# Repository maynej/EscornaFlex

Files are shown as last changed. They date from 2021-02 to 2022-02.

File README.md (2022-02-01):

# EscornaFlex

EscornaFlex es una modificació de l'estructura original de Escornabot amb la flexibilitat de poder portar una placa de control 2.12 o 2.20, un sensor de distància per ultrasons i un lector RFID 

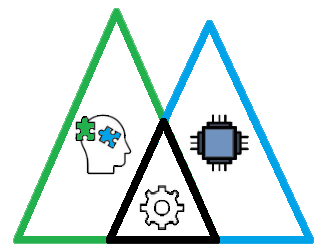
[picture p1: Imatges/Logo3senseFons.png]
Realitzada per [Jordi Mayné](https://github.com/maynej) des de Mechatronic Study 

Escornabot es un projecte obert (https://escornabot.com) 

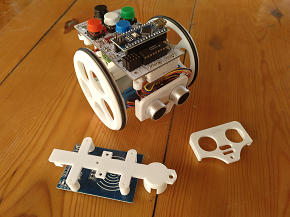
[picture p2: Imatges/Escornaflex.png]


Tota la [documentació es pot trobar en PDF](https://github.com/maynej/EscornaFlex/tree/master/Doc/). Inclós en llengua castellana.

STL per imprimir [aquí](https://github.com/maynej/EscornaFlex/tree/master/stl).

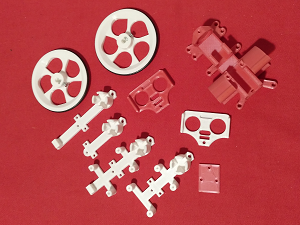
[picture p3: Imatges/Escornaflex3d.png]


## Llicència

Creative Commons Attribution-NoComercial-ShareAlike 4.0 International (CC BY-NC-SA 4.0)

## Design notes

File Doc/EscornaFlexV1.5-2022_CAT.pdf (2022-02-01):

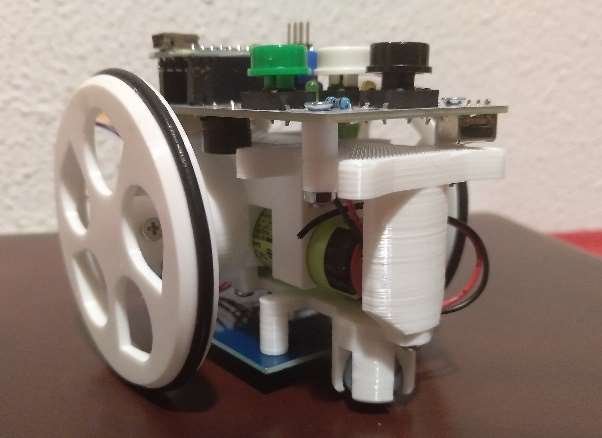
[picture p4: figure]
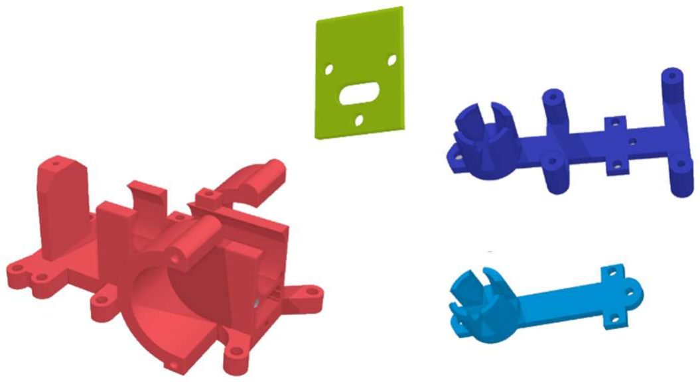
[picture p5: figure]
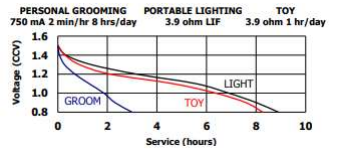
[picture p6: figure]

1 | EscornaFlex V.1.5 - 2022 | Jordi Mayné

## EscornaFlex

És un nou Escornabot ?, no. És una evolució de l'estructura Singularis, amb la particularitat de poder posar la placa CPU 2.12 o la CPU 2.20, per donar millor cabuda a les aplicacions amb Wifi o BT que a causa del seu consum es reduïa molt la vida de les piles, i més quan se li afegeix el lector de RFID, o noves aplicacions que aniran apareixent.

Para veure una mica aquests consums:
El mòdul BT HM-10 v4.0 en mode dormit consumeix 60uA, en mode actiu 8,5mA, però en mode RX està sobre els 15mA i en TX pot arribar a més de 25mA. Els consums depenen de la velocitat de transmissió, potencia de sortida i temps en espera i funcionament.
El mòdul Wifi ESP01 te diversos modes dormit que van des de 10uA fins 15mA, en mode RX està sobre els 56mA i en TX entre 120 y 170mA.
El mòdul RFID RC522 també te molts modes de treball, però tal com es farà servir en l’Escornabot s’utilitza com lector principalment que està sobre els 30mA y mentre espera una lectura pot estar entre 80uA fins a 4mA.
En definitiva, estem afegint consums importants, encara que siguin en temps “curts” , que minvarà la vida de las piles significativament. Les piles alcalines admeten un consum regular i el que menys els agrada son les puntes de corrent.
La solució es fer servir una bateria de Li-Ion que permet una major capacitat de carrega amb les mateixes dimensions. Anem a veure les diferencies:
Piles alcalines tipus AA (LR6) utilitzades fins ara, cada cèl·lula te unes dimensions de 14,5mm de diàmetre i 50,5mm de llarg, amb un pes de 23gr. El voltatge es de 1,5V i poden entregar entre 1700mAh i 3000mAh depenent del fabricant, i es necessiten 4 muntades en sèrie per donar un voltatge de sortida de 6V, però com es pot veure en la gràfica d’un fabricant, el voltatge va caient amb el consum i en el temps. Es a dir, els 6V duraran poc temps.

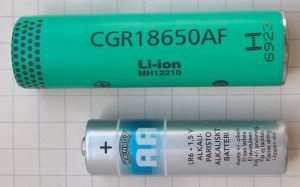
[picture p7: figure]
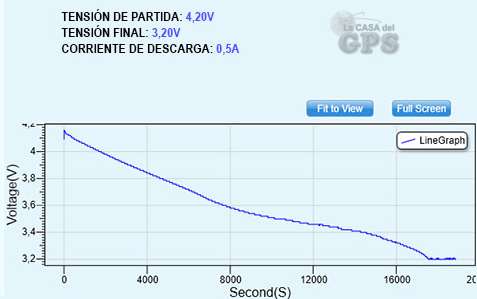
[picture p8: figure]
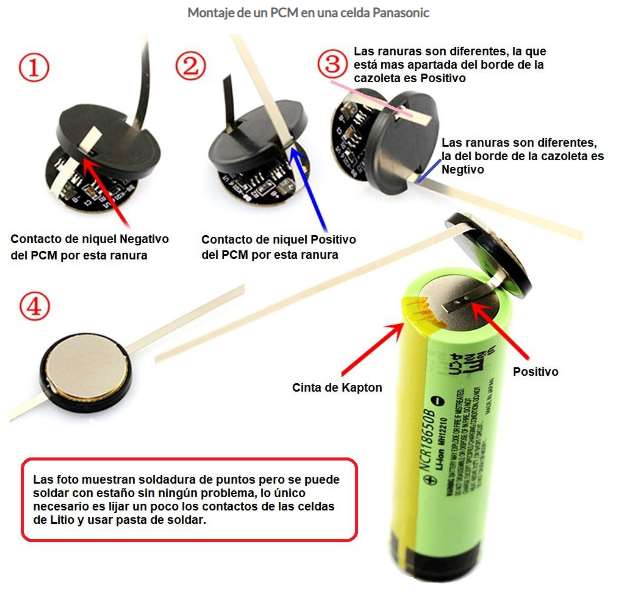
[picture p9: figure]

2 | EscornaFlex V.1.5 - 2022 | Jordi Mayné

Bateries Li-Ion tipus 18650 son de 3,7V i poden entregar entre 2000 i fins a 9000mAh, tenen unes dimensions de 18mm de diàmetre i 65mm de llarg, amb un pes de 49gr, son més cares que les piles (relativament) ja que son recarregables. Aquest model 18650 s’utilitza massivament en molts equips electrònics, com ordinadors portàtils, patinets i bicicletes elèctriques, llanternes, power-bank…

La gràfica mostra que, connectant una carrega de 0,5A al cap de 4,5h la tensió de la bateria arribarà als 3.2V amb que encara li queda carrega fins els 2.75V, que es la mínima permesa.
Un detall molt important, como sempre la seguretat. Les bateries Li-Ion poden “explotar”. Però no cal espantar-se, hi ha que fer les coses be. Per que “exploti” pot ser degut per les causes següents:
1. Curtcircuit (es pot evitar fent servir un circuit PCM o col·locant un fusible re-armable just en el terminal de la bateria).
2. Sobrevoltatge en la carrega, es a dir carregar-la amb un voltatge superior a l’especificada de 4.22V (es pot evitar fent servir un circuit de carrega apropiat).
3. Temperatura de la bateria (evitant una font de calor propera a ella).

Es poden comprar bateries 18650 amb la
protecció incorporada, per no confondre és
molt fàcil de detectar si la inclou o no, simplement per la longitud, en lloc de mesurar 65mm passa a tenir 69mm en incorporar el circuit de protecció.
Les bateries que inclouen protecció són per anar en un "porta-bateries", és a dir sense terminals per soldar, fins ara no s'han trobat que l'incorporin en les bateries amb terminals, però pot ser que en breu es trobin també en aquest tipus .
Una solució és incorporar un circuit PCM, que protegeix contra curtcircuits, sobre-voltatges i obre el circuit quan arriba la bateria a 2,75V.

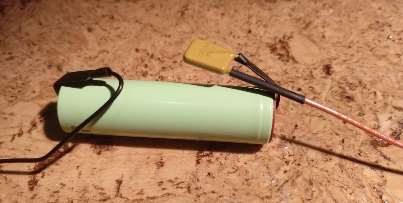
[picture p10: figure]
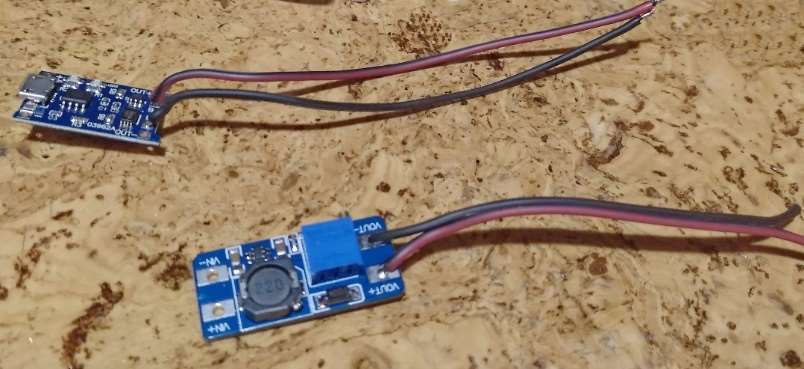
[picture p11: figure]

3 | EscornaFlex V.1.5 - 2022 | Jordi Mayné

Una altra solució no tan sofisticada i més senzilla és posar un fusible rearmable de 0,65A al terminal de la bateria, protegirà només contra curtcircuits, però suficient.

Circuit de control:

Per carregar la bateria es parteix d'una connexió USB, que és de 5V, i amb un circuit mòdul de càrrega TP4056 que protegeix perquè no pugui arribar a la bateria un voltatge superior a 4,2V i que no li pugui arribar un corrent de càrrega superior a 1A.
La bateria lliura un voltatge entre 3 fins 4,2V, i amb un altre mòdul MT3608 Step-up puja el voltatge regulat a 6V (el valor de sortida s’ajusta amb el potenciòmetre que
inclou. Aquest circuit admet voltatge de 2 a 24V d'entrada i la sortida ajustable entre
5 fins 28V, amb un corrent fins 2A.
La sortida d’aquest circuit pot conectarse (una vegada ajustat a 6V) a l’entrada de la pcb CPU.

Nota important: S’ha detectat que algun step-up no aguanta les puntes de corrent dels motors, i no funciona l’Escornabot, nomès les llums i el pitu del brunzidor. Llavors es soluciona col.locant un condensador electrolític de 1000uF 10V en les bornas d’alimentació.

Preparació del muntatge:
Abans de soldar les connexions entre les plaques, cal revisar si entren bé les plaques en la guia suport que hi ha sota la bateria de l'estructura, depèn del fabricant de les plaques pot entrar molt justa o no tant, es pot solucionar llimant els laterares del pcb de la placa. Un cop ajustades, es pot començar a realitzar les connexions.
Primer soldar a la placa USB els cables a B+ i B- que aniran a la bateria i en la placa step-up els cables en Vout+ i Vout- que aniran al connector de la placa CPU.

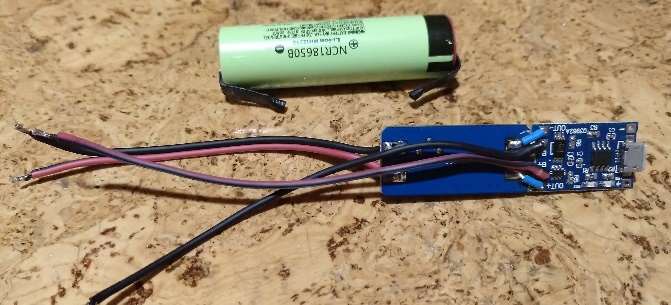
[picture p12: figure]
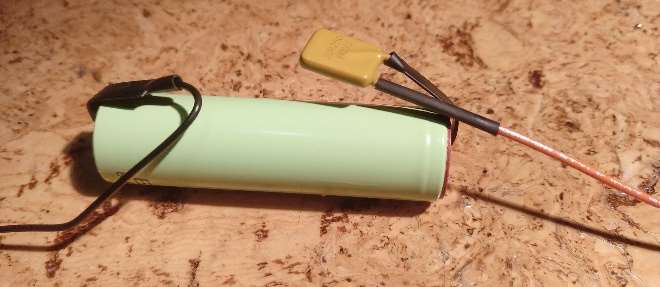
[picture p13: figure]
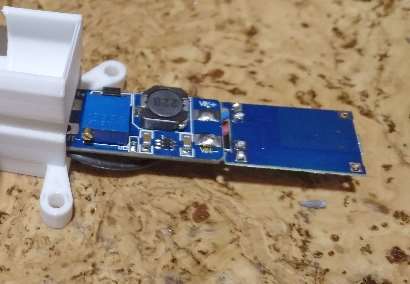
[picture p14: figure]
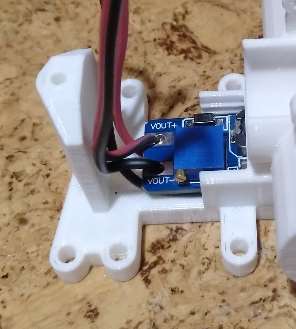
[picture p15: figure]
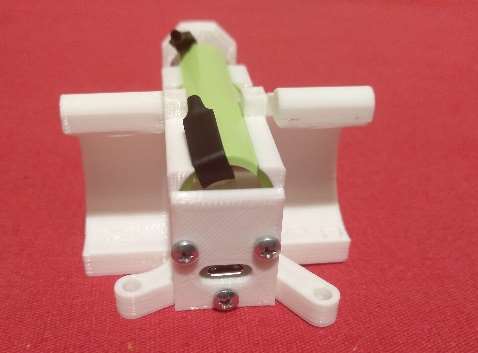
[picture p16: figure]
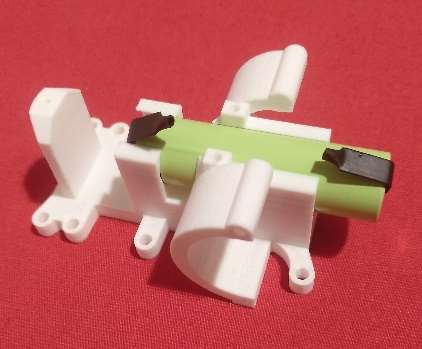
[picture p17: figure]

4 | EscornaFlex V.1.5 - 2022 | Jordi Mayné

Seguidament col·locar la placa de càrrega USB en posició amb els components en la part superior i la placa step-up amb els components en la part inferior, així coincidiran les sortides Out+ i Out- del carregador amb Vin+ i Vin- del step-up, amb fil rígid fer aquestes connexions (a la foto es poden apreciar de color blau). Es fan amb fil rígid perquè formin un bloc compacte per poder-les inserir en l'estructura, ja que entrarà expressament molt justes perquè no es desplacin.

Soldar un fusible rearmable de 0,65A al positiu de la bateria i aïllar amb tub termoretàctil aquestes connexions.

Inserir les dues plaques en l'estructura amb totes les connexions realitzades, entrarà molt justa, col·locar els cables molt plans per ajudar a que llisqui bé.

D’aquesta manera quedarà accesible el potenciómetre d’ajust de la tensió de sortida, que s’ajustará a 6V. Col·locar la bateria en el habitacle desplaçant-la fins al final.

Col·locar la tapa que cobrirà el connector USB i la bateria

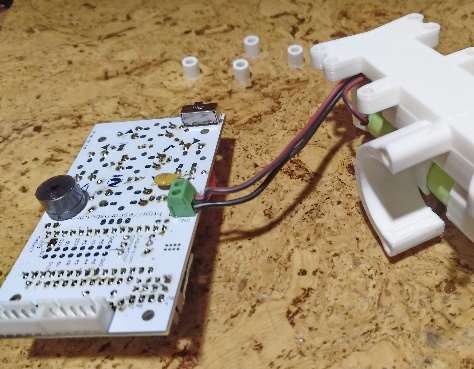
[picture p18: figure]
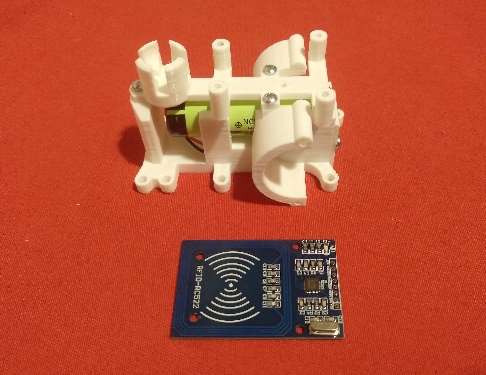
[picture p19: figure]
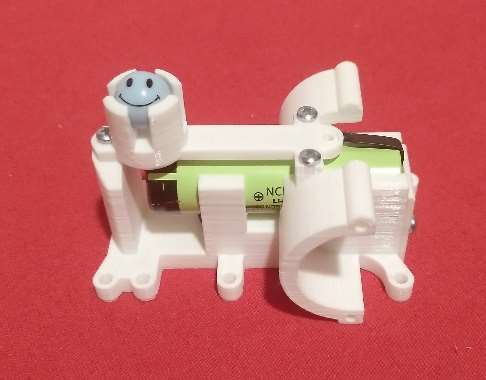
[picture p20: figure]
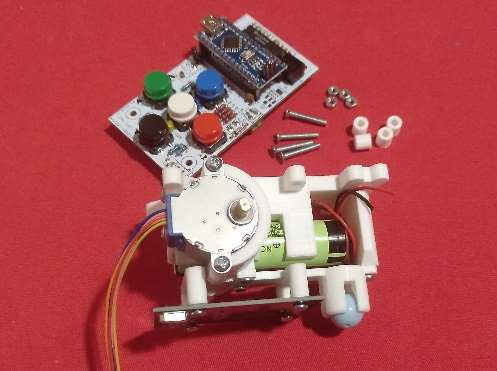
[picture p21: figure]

5 | EscornaFlex V.1.5 - 2022 | Jordi Mayné

Connectar els cables de sortida de la placa step-up al connector d’alimentació de la CPU. Soldar els cables de la placa de USB B+ al fusible rearmable de la batería i B- al negatiu.

Hi ha dues opcions del suport de bola “boja”, per incorporar la placa de RFID RC522 o sense.

Es munten els motors i la placa CPU corresponent (2.12 o 2.20) amb l’ajut de 4 separadors i 4 cargols M3x20 y 4 femelles M3.

Es connecten els cables de cada motor al seu connector corresponent (motor dret a la dreta i motor esquerra a l’esquerra).

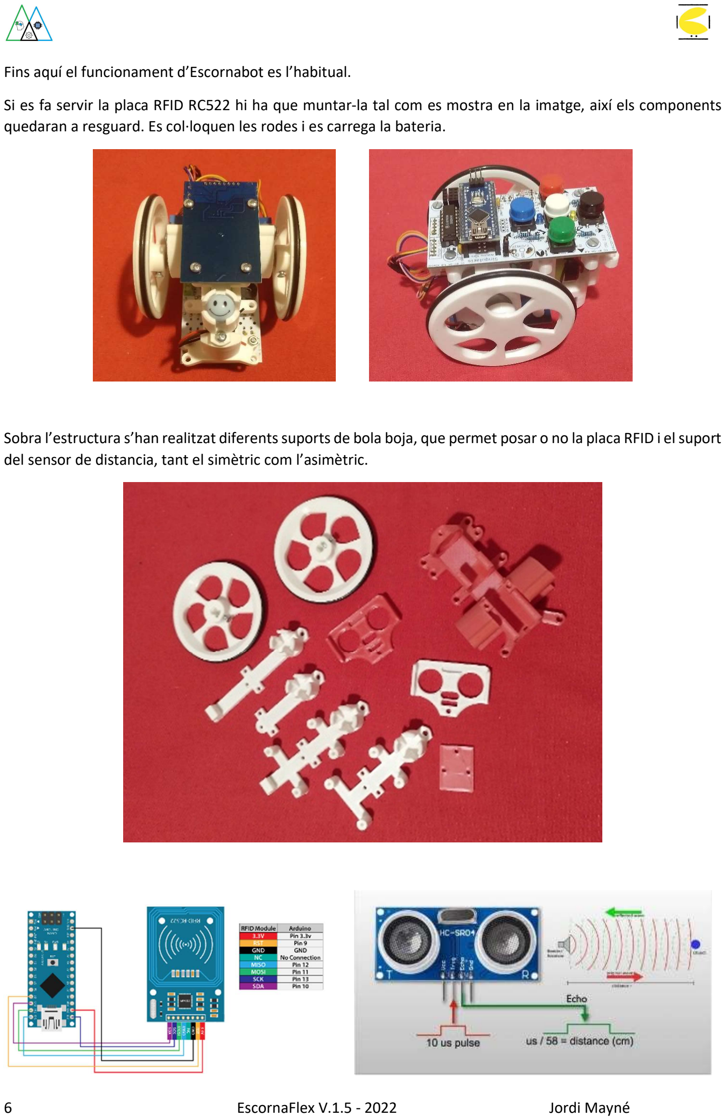
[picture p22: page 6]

6 | EscornaFlex V.1.5 - 2022 | Jordi Mayné

Fins aquí el funcionament d’Escornabot es l’habitual.
Si es fa servir la placa RFID RC522 hi ha que muntar-la tal com es mostra en la imatge, així els components quedaran a resguard. Es col·loquen les rodes i es carrega la bateria.

Sobra l’estructura s’han realitzat diferents suports de bola boja, que permet posar o no la placa RFID i el suport del sensor de distancia, tant el simètric com l’asimètric.

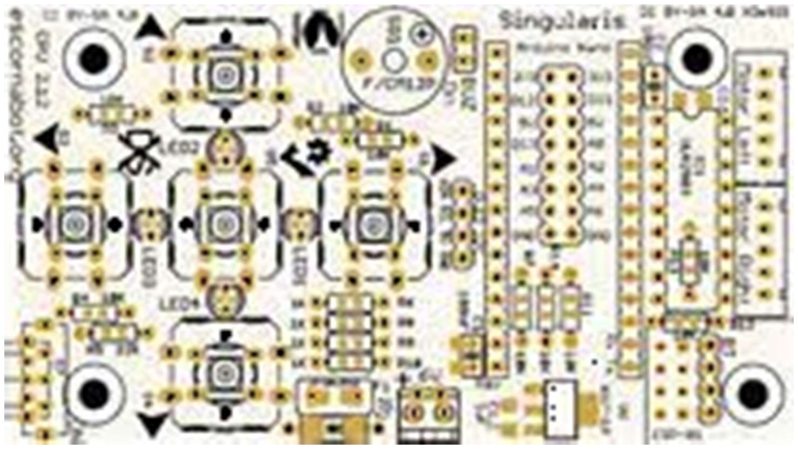
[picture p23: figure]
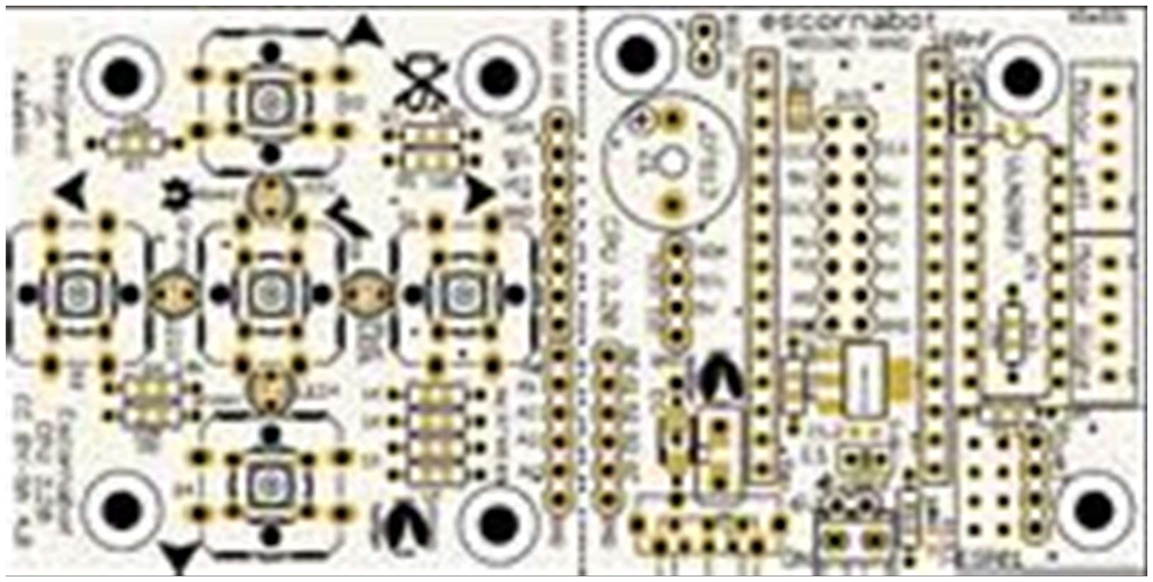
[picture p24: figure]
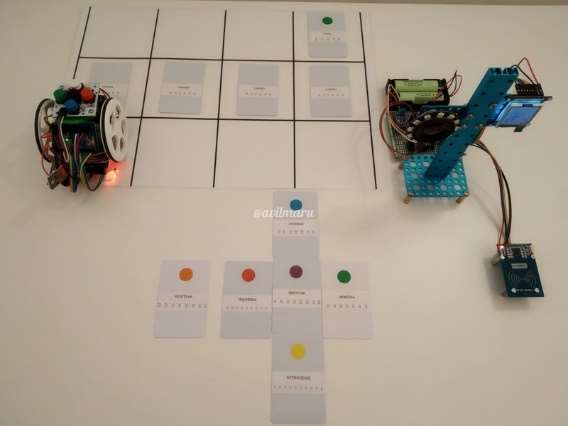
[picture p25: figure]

7 | EscornaFlex V.1.5 - 2022 | Jordi Mayné

Es pot utilitzar tant el mòdul de Wifi como el de Bluetooth, però, es més recomanable usar el de Bluetooth i l’aplicació per Android.

Mòdul Wifi | Mòdul Bluetooth i aplicació per Android

En quant les plaques CPU que es poden muntar es mostren a continuació.

CPU 2.12 | CPU2.20

Tota la documentació i els STL es troba disponible en el github: https://github.com/maynej/EscornaFlex

Per el funcionament RFID referir-se al bon treball d’Ángel Villanueva en el “Proyecto para niños y niñas con discapacidad visual o ceguera”.

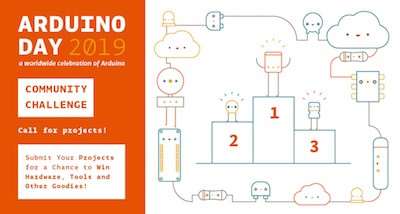
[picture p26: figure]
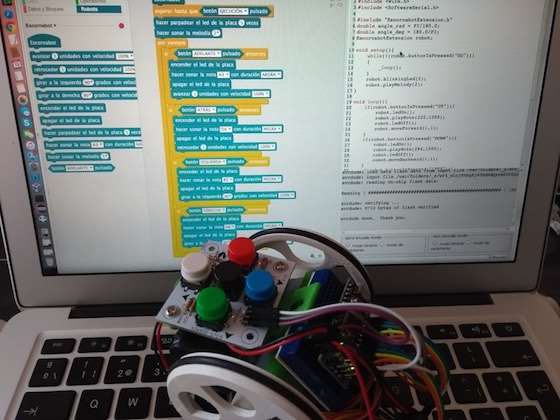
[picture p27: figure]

8 | EscornaFlex V.1.5 - 2022 | Jordi Mayné

Aquest projecte va ser presentat en el concurs internacional “Arduino Day Community Challenge” el dissabte 16 de Març de 2019 a Milà resultant guanyador en la categoria d’innovació social.

http://www.mecatronicalab.es/escornabot-proyecto-para-ninos-con-discapacidad-visual-o-ceguera/ A més, la magnífica aplicació EscornaVoz: http://www.mecatronicalab.es/escornavoz/

i l’extensió per Programar ESCORNABOT AMB MBLOCK basat en Scratch 2.0 http://www.mecatronicalab.es/programando-escornabot-con-mblock/

¡¡¡Moltes gràcies a tots els col·laboradors del projecte Escornabot, fa que dia a dia segueixi creixent !!!

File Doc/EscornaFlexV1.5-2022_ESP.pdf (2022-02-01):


1 | EscornaFlex V.1.5 - 2022 | Jordi Mayné

## EscornaFlex

¿Es un nuevo Escornabot?, no. Es una evolución de la estructura Singularis, con la particularidad de poder poner la placa CPU 2.12 y la CPU 2.20, para dar mejor cabida a las aplicaciones con Wifi o BT que debido a su consumo se reducía mucho la vida de las pilas, y más cuando se le añade el lector de RFID, o nuevas aplicaciones que irán apareciendo.

Para ver un poco estos consumos:
El módulo BT HM-10 v4.0 en modo dormido consume 60uA, en modo activo 8,5mA, pero en modo RX está sobre los 15mA y en TX puede llegar a más de 25mA. Los consumos dependen de la velocidad de transmisión, potencia de salida y tiempo en espera y funcionamiento.
El módulo Wifi ESP01 tiene varios modos de trabajo “dormido” que van desde los 10uA hasta los 15mA, en modo RX está sobre los 56mA y en TX entre 120 y 170mA.
El módulo RFID RC522 también tiene muchos modos de trabajo, pero en su uso actual en el Escornabot se utiliza como lector principalmente que está sobre los 30mA y mientras espera una lectura puede estar entre 80uA hasta los 4mA.
En definitiva, estamos añadiendo consumos importantes, aunque sean en tiempos “cortos”, que mermarán la vida de las pilas significativamente. Las pilas alcalinas admiten un consumo regular y lo que menos les gusta son las puntas de corriente.
La solución es usar un batería de Li-Ion que permiten una mayor capacidad de carga con el mismo tamaño. Vamos a ver las diferencias:
Pilas alcalinas tipo AA (LR6) utilizadas hasta ahora, cada célula tiene un tamaño de 14,5mm de diámetro y 50,5mm de largo, con un peso de 23gr. El voltaje es de 1,5V y pueden entregar entre 1700mAh y 3000mAh dependiendo del fabricante, y se necesitan 4 montadas en serie para dar un voltaje de salida de 6V, pero como se puede ver en la gráfica de un fabricante, el voltaje va cayendo con el consumo y en el tiempo. Es decir, los 6V durarán poco tiempo.


2 | EscornaFlex V.1.5 - 2022 | Jordi Mayné

Baterías Li-Ion tipo 18650 son de 3,7V y pueden entregar entre 2000 y hasta 9000mAh, tienen un tamaño de 18mm de diámetro y 65mm de largo, con un peso de 49gr, son más caras que las pilas (relativamente) ya que son recargables. Este modelo 18650 se utiliza masivamente en muchos equipos electrónicos, como ordenadores portátiles, patinetes y bicicletas eléctricas, linternas, power-bank…

La gráfica muestra que, conectando una carga de 0,5A al cabo de 4,5h la tensión de la batería llegará a los 3,2V, con lo que aún le queda carga hasta llegar a los 2,75V, que es la mínima permitida.
Un detalle muy importante, como siempre la seguridad. Las baterías Li-Ion pueden “explotar”. Pero no hay que asustarse, hay que hacer las cosas bien. Para que “explote” puede ser debido por las causas siguientes:
1. Cortocircuito (se puede evitar usando un circuito PCM o un colocando un fusible re-armable justo en el terminal de la batería).
2. Sobrevoltaje en la carga, es decir cargarla con un voltaje superior a la especificada 4.22V (se puede evitar usando un circuito de carga apropiado).

### 3. Temperatura de la batería (se

puede evitar evitando una fuente
de calor próxima a ella).Se pueden
comprar baterías 18650 con la protección incorporada, para no confundirse es muy fácil de detectar si la incluye o no, simplemente por la longitud, en lugar de medir 65mm pasa a tener 69mm al incorporar el circuito de protección.
Las baterías que incluyen protección son para ir en un “porta-baterías”, es decir sin terminales para soldar, hasta ahora no se han encontrado que lo incorporen en las baterías con terminales, pero puede ser que en breve se encuentren también en este tipo.


3 | EscornaFlex V.1.5 - 2022 | Jordi Mayné

Una solución es incorporar un circuito PCM, que protege contra cortocircuitos, sobrevoltajes y abre el circuito cuando llega la batería a 2,75V.
Otra solución no tan sofisticada y más sencilla es poner un fusible re-armable de 0,65A en el terminal de la batería, protegerá solamente contra cortocircuitos, pero suficiente.

Circuito de control:

Para cargar la batería se parte de una conexión USB, que es de 5V, y con un circuito módulo de carga TP4056 que protege para que no pueda llegar a la batería un voltaje superior a 4,2V y que no le pueda llegar una corriente de carga superior a 1A.
La batería entrega un voltaje entre 3 hasta 4,2V, entonces con otro módulo MT3608 Step-up sube el voltaje regulado a 6V (es ajustable el valor de salida, ajustando el potenciómetro que incluye. Este circuito admite voltaje de 2 a 24V de entrada y la
salida ajustable entre 5 hasta 28V, con una corriente hasta 2A.
La salida de este circuito puede conectarse (una vez ajustado a 6V) a la entrada de la pcb CPU.

Nota importante: Se ha detectado que algun step-up no aguanta las puntas de corriente de los motores, y entonces no funciona el Escornabot, solo las luces y el pitido del zumbador. Entonces se soluciona colocando un condensador electrolítico de 1000uF 10V en las bornas de alimentación.
Preparación del montaje:
Antes de soldar las conexiones entre las placas, hay que revisar si entran bien las placas en la guía soporte que hay debajo de la batería de la estructura, depende del fabricante de las placas puede entrar muy justa o no tanto, se puede solucionar limando los laterares del pcb de la placa. Una vez ajustadas, se puede empezar a realizar las conexiones.
Primero soldar en la placa USB los cables en B+ y B- que irán a la batería y en la placa step-up los cables en Vout+ y Vout- que irán al conector de la placa CPU.


4 | EscornaFlex V.1.5 - 2022 | Jordi Mayné

Seguidamente colocar la placa de carga USB en posición con los componentes en la parte superior y la placa step-up con los componentes en la parte inferior, así coincidirán las salidas Out+ y Out- del cargador con Vin+ y Vin- de step-up, con hilo rígido hacer estas conexiones (en la foto se pueden apreciar de color azul). Se hacen con hilo rígido para que formen un bloque compacto para poderlas insertar en la estructura, ya que entrará expresamente muy justas para que no se desplacen.

Soldar un fusible rearmable de 0,65A en el positivo de la batería y aislar con tubo termoretàctil estas conexiones.

Insertar las dos placas en la estructura con todas las conexiones realizadas, entrará muy justa, colocar los cables muy planos para ayudar a que se deslice bien.

De esta manera quedará accesible el potenciómetro de ajuste de la tensión de salida, que se ajustará a 6V. Colocar la batería en el habitáculo desplazando la batería por el habitáculo.

Colocar la tapa que cubrirá el conector USB y la batería


5 | EscornaFlex V.1.5 - 2022 | Jordi Mayné

Conectar los cables salida de la placa step-up al conector de alimentación de la CPU. Soldar los cables de la placa de USB B+ al fusible rearmable de la batería y B- al negativo.

Hay dos opciones del soporte de bola “loca”, para incorporar la placa de RFID RC522 o sin.

Se montan los motores y la placa CPU correspondiente (2.12 o 2.20) con la ayuda de 4 separadores y 4 tornillos M3x20 y 4 tuercas M3.

Se conectan los cables de cada motor a su conector correspondiente (derecho a la derecha e izquierdo a izquierda).


6 | EscornaFlex V.1.5 - 2022 | Jordi Mayné

Hasta aquí el funcionamiento del Escornabot es el habitual.
Si se usa la placa RFID hay que montarla tal como se muestra en la imagen, así los componentes quedarán a salvo. Se colocan las ruedas y se carga la batería. El funcionamiento de Escornabot es el habitual.

Sobre la estructura se han realizado diferentes soportes de bola loca, que permite insertar o no la placa RFID y el soporte del sensor de distancia, tanto el simétrico o asimétrico.


7 | EscornaFlex V.1.5 - 2022 | Jordi Mayné

Se puede usar tanto el módulo de Wifi como el de Bluetooth, pero es más recomendable usar el de Bluetooth y la aplicación de Android.

Módulo Wifi | Módulo Bluetooth y aplicación para Android

En cuanto a las placas CPU que se pueden montar se muestran a continuación.

CPU 2.12 | CPU2.20

Toda la documentación y STL se encuentra disponible en el github: https://github.com/maynej/EscornaFlex

Para el funcionamiento RFID referirse al buen trabajo de Ángel Villanueva en el “Proyecto para niños y niñas con discapacidad visual o ceguera”.


8 | EscornaFlex V.1.5 - 2022 | Jordi Mayné

Este proyecto fue presentado en el concurso internacional “Arduino Day Community Challenge” celebrado el sábado 16 de marzo de 2019 en Milán resultando ganador en la categoría de innovación social.

http://www.mecatronicalab.es/escornabot-proyecto-para-ninos-con-discapacidad-visual-o-ceguera/

Además, la magnífica aplicación EscornaVoz http://www.mecatronicalab.es/escornavoz/

y la extensión para Programar ESCORNABOT CON MBLOCK basado en Scratch 2.0 http://www.mecatronicalab.es/programando-escornabot-con-mblock/

¡¡¡Muchas gracias a todos los colaboradores del proyecto Escornabot, hace que día a día siga creciendo!!!

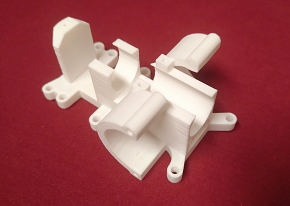
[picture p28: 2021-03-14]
Imatges/CosEscornaflex.png

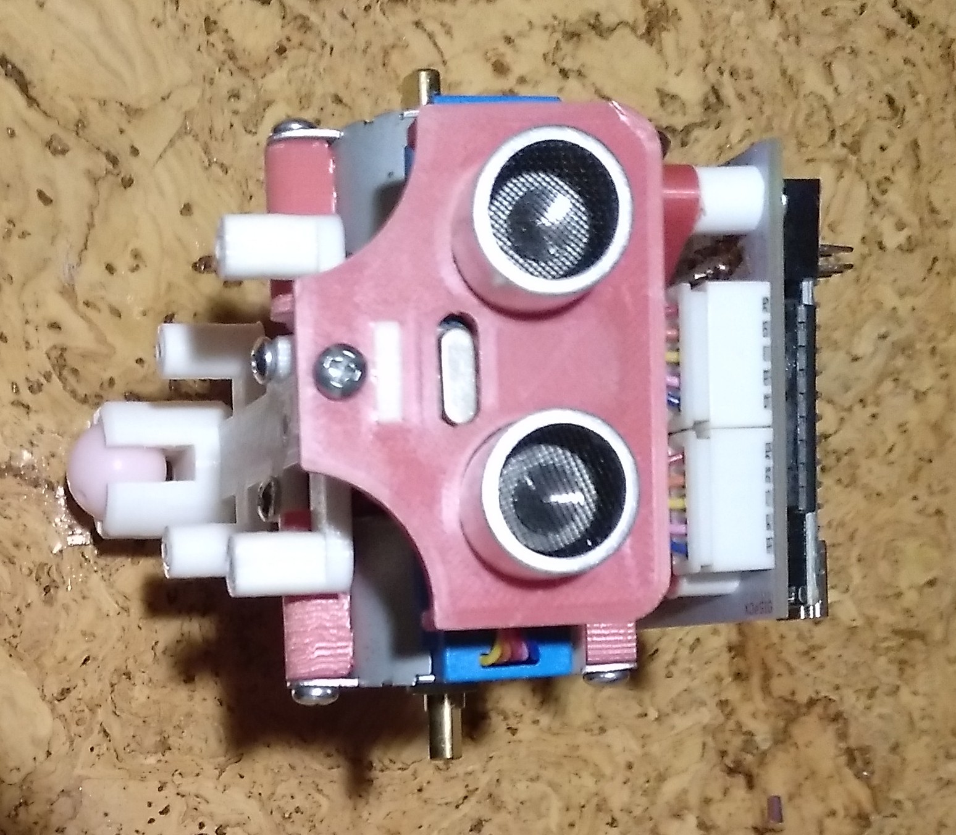
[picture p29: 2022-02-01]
Imatges/MVIMG_20191003_181412_255~2.jpg

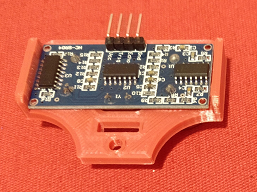
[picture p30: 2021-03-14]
Imatges/SensorUltrasons.png

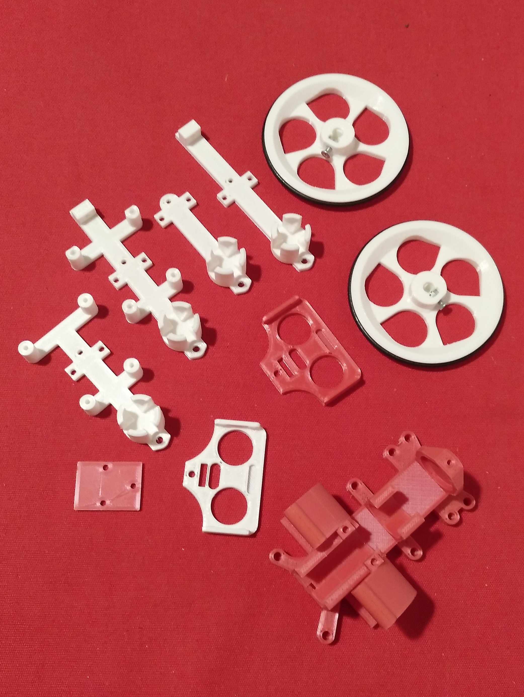
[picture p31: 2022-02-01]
Imatges/MVIMG_20191001_185606_342_2.jpg

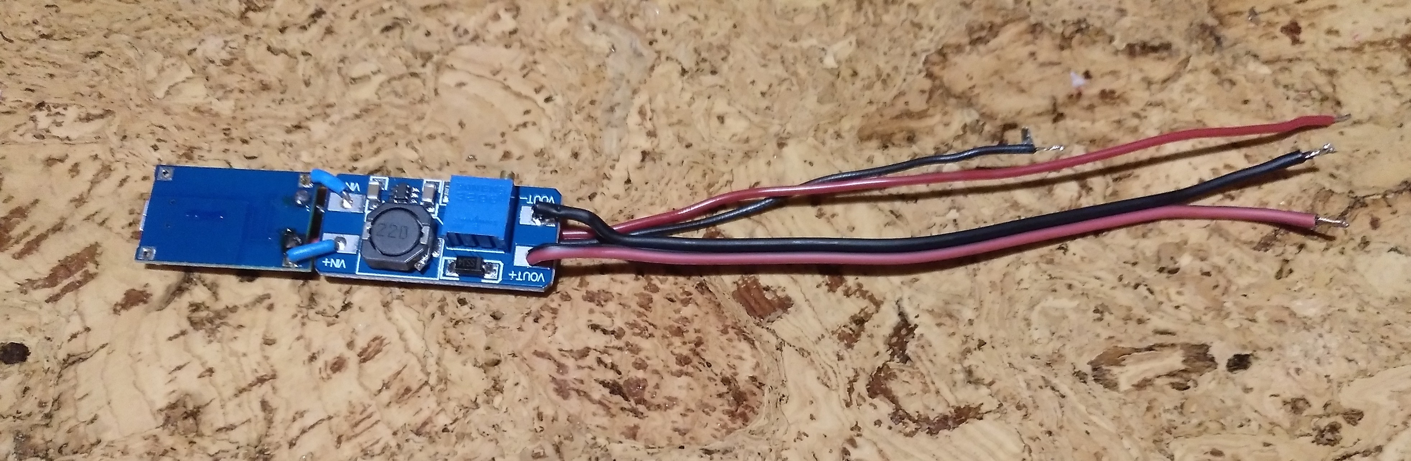
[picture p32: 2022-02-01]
Imatges/MVIMG_20191001_230914_665_2.jpg

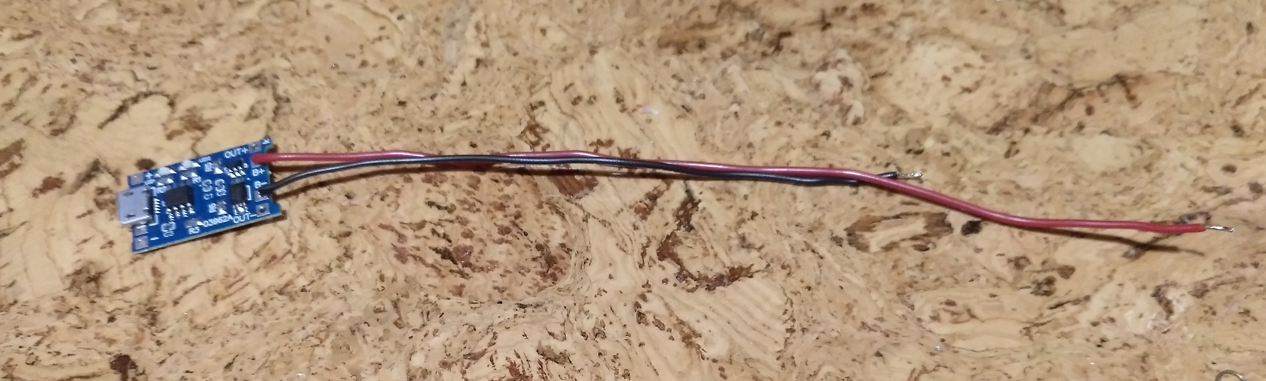
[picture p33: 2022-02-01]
Imatges/MVIMG_20191001_210524_707_2.jpg

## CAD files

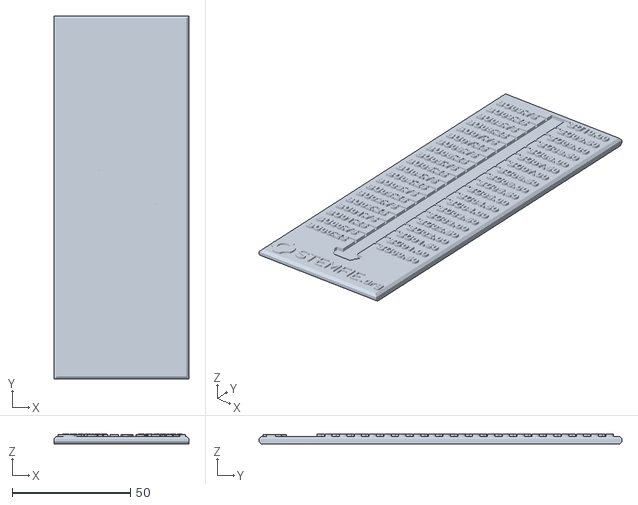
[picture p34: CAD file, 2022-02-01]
stl/MesuraStemfie2.stl
57.0 x 153.4 x 4.13

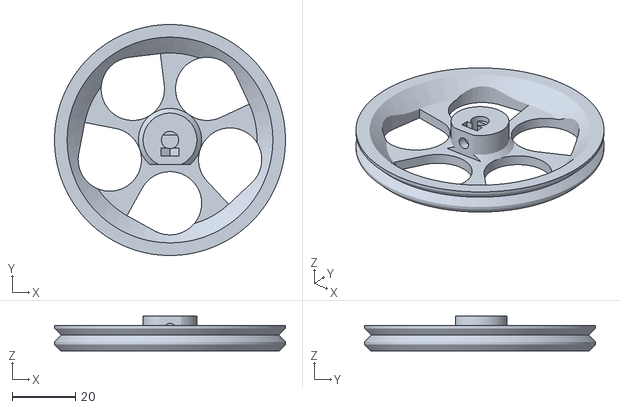
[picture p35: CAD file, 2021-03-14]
stl/wheel-r.stl
73.0 x 73.0 x 11.0

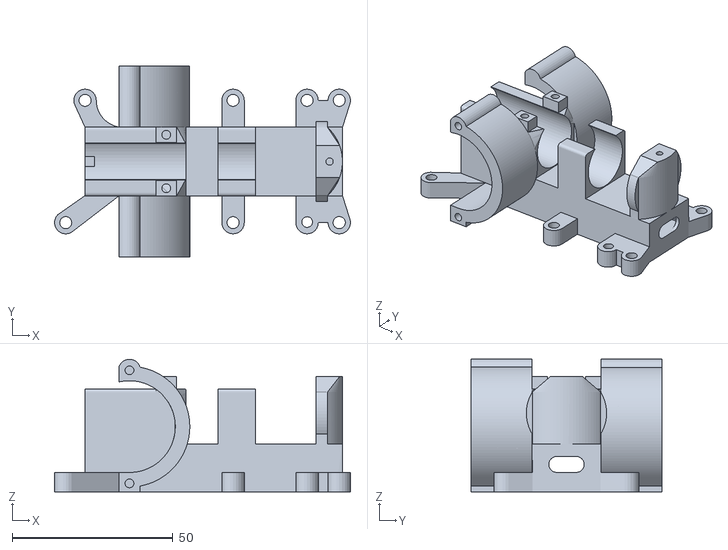
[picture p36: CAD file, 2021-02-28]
stl/EscornaFlexV2.stl
92.0 x 59.4 x 41.2

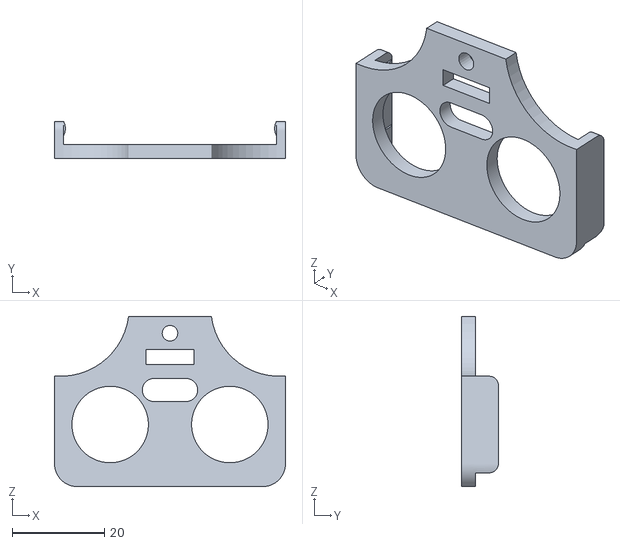
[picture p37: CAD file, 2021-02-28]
stl/EscornaflexSensorSimetrico.stl
50.2 x 8.00 x 37.0

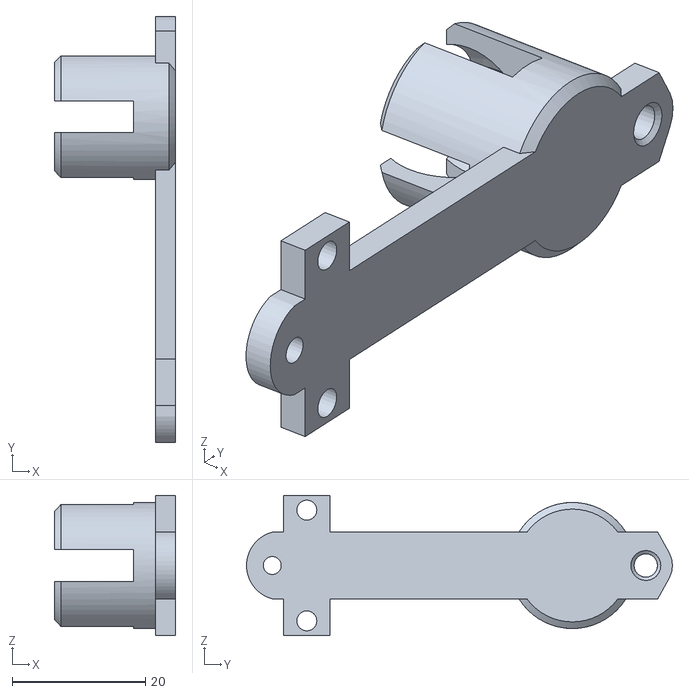
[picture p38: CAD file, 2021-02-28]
stl/EscornaflexV1_Bola.stl
18.2 x 63.8 x 21.0

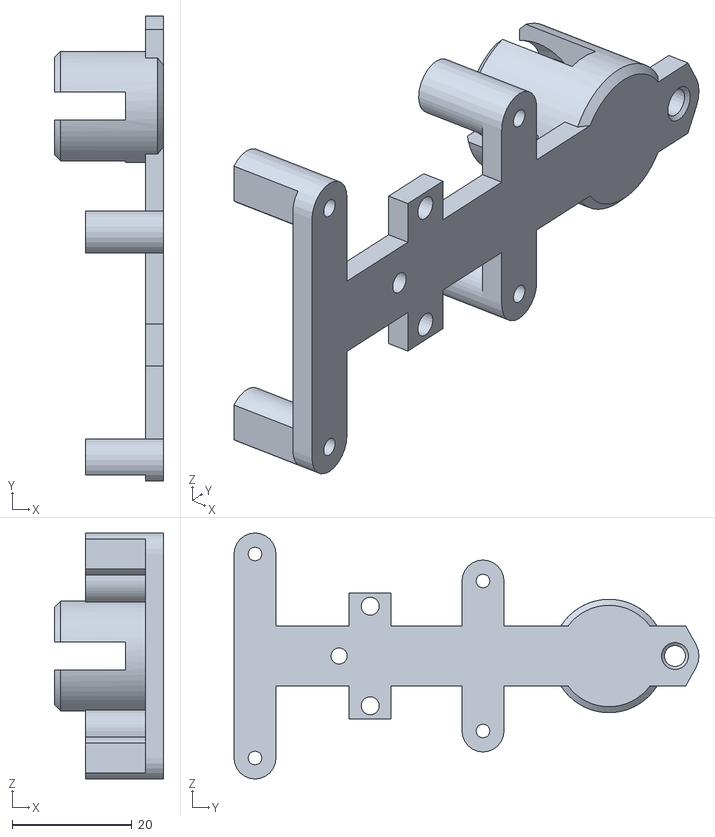
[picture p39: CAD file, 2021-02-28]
stl/EscornaflexV1_BolaRFID.stl
18.2 x 77.5 x 41.0

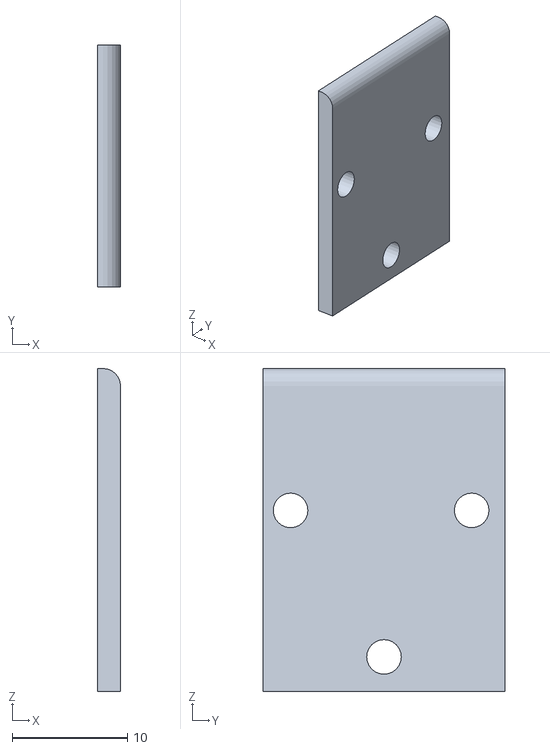
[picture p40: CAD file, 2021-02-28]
stl/EscornaflexV2_Tapa.stl
2.00 x 21.0 x 28.0

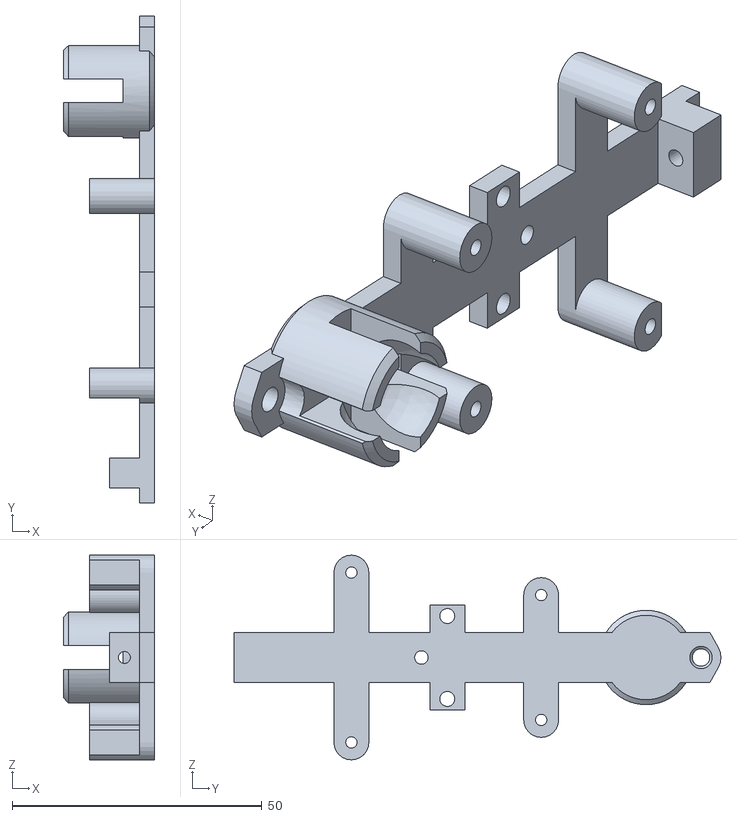
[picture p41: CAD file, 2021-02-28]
stl/EscornaflexV1_BallRFID2.stl
18.2 x 97.5 x 41.0

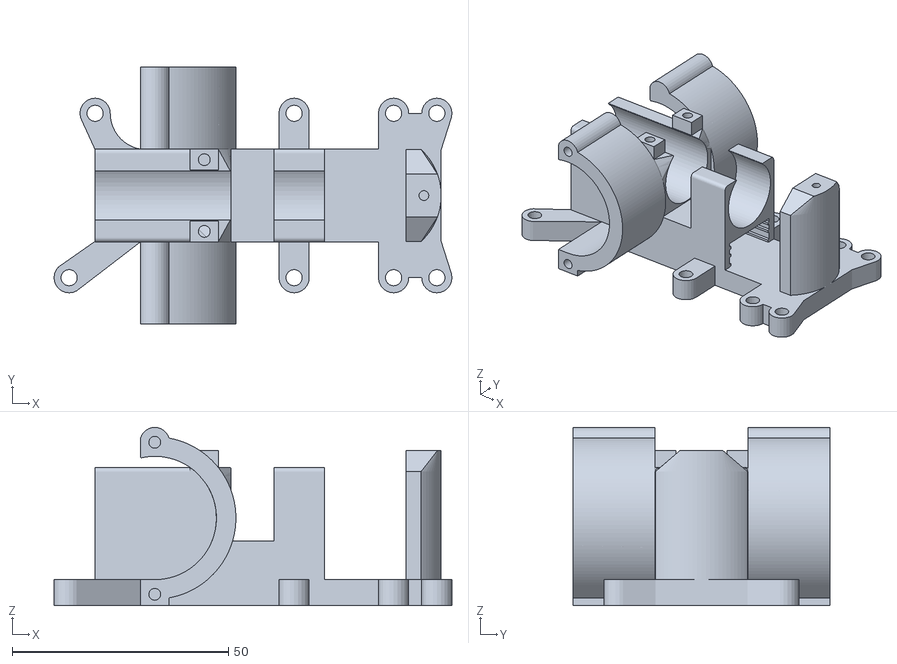
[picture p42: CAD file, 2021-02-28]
stl/EscornaflexV1_estructura.stl
92.0 x 59.4 x 41.2

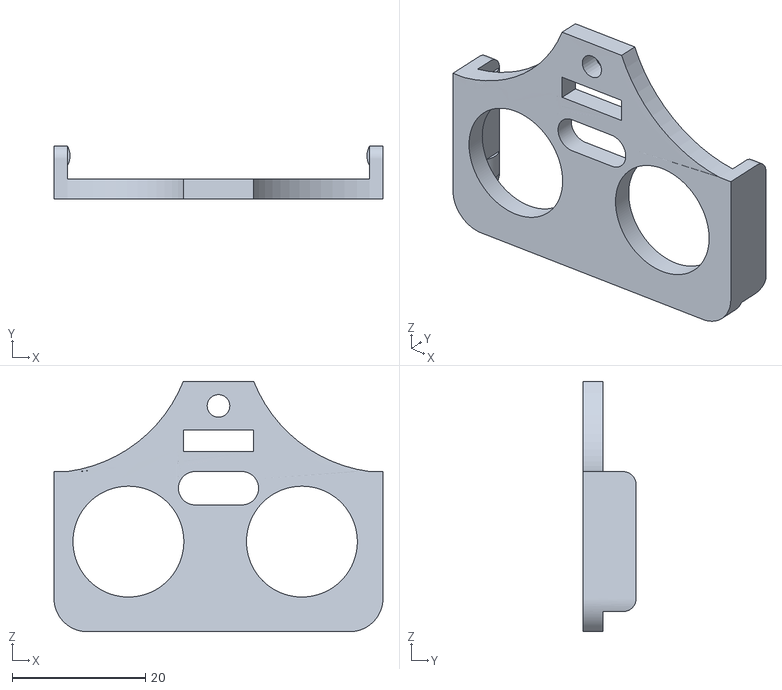
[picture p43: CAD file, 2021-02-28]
stl/EscornaflexSensorAsimetrico.stl
49.3 x 8.00 x 37.5

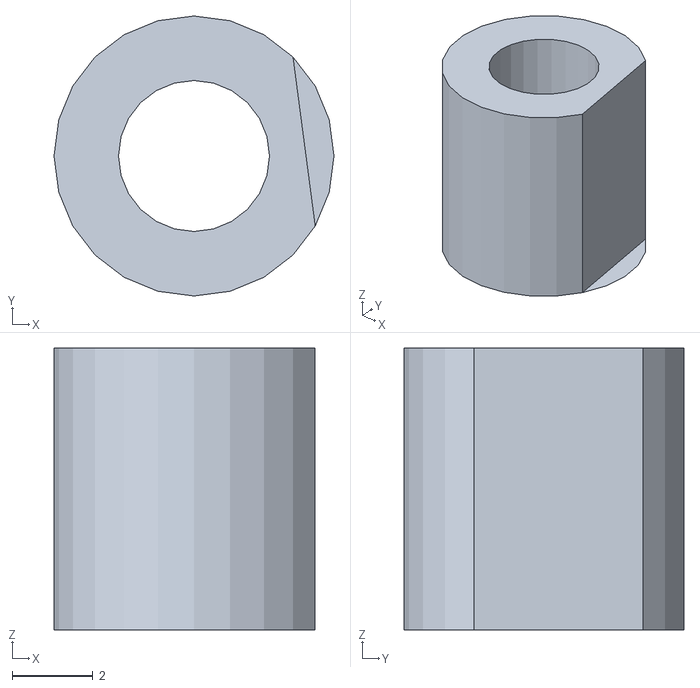
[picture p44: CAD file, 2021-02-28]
stl/EscornaflexV1_Separador3x7mm.stl
6.95 x 6.95 x 7.00

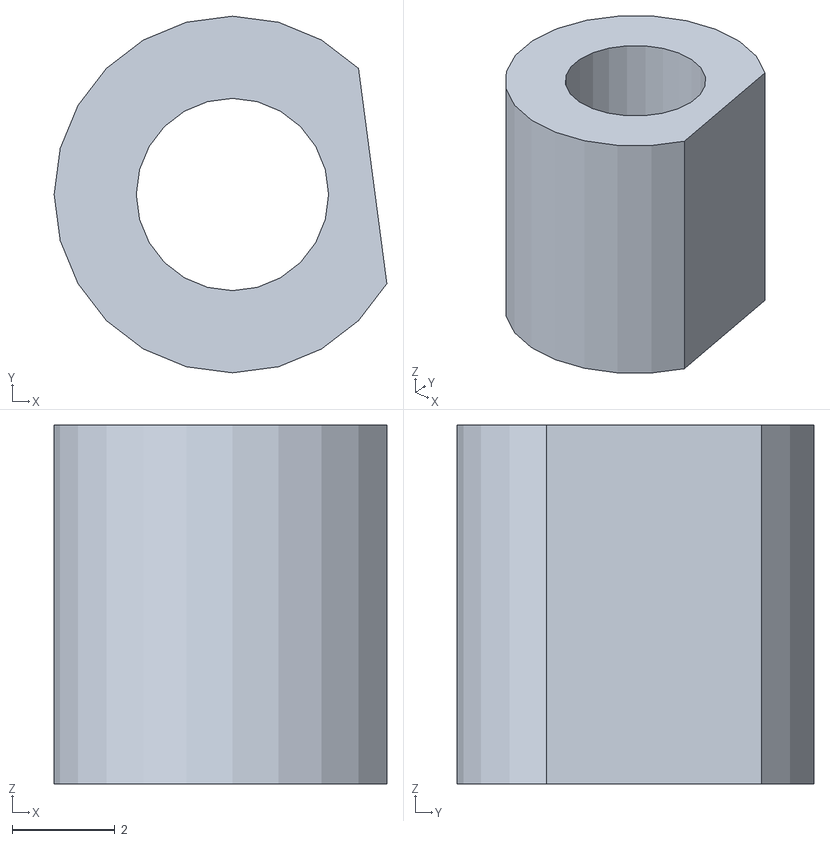
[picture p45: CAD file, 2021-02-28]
stl/EscornaflexV1_Separador1x7mmSwitch.stl
6.49 x 6.95 x 7.00

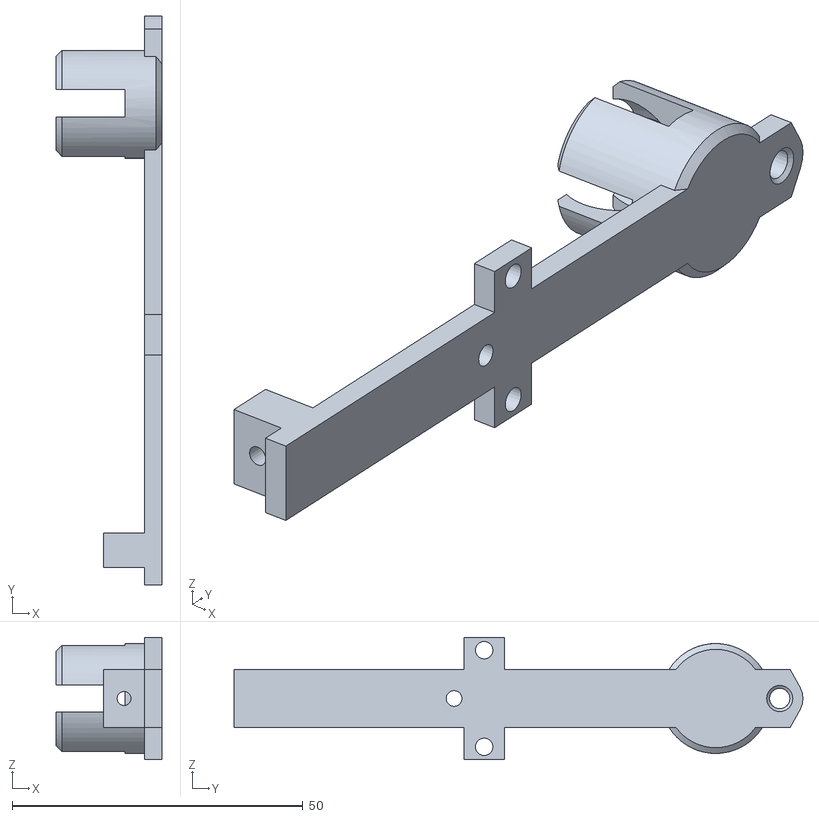
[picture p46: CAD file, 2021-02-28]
stl/EscornaflexV1_Ball2.stl
18.2 x 97.8 x 21.0

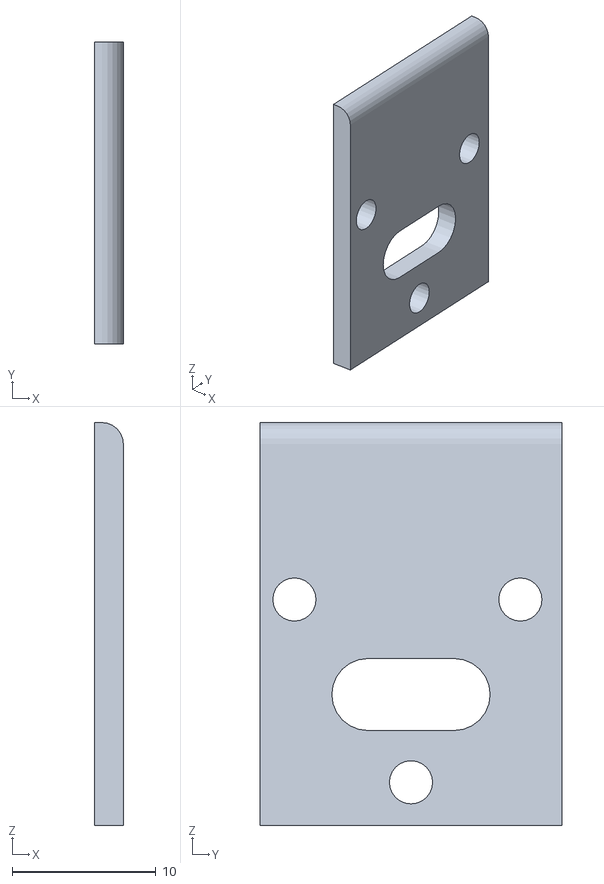
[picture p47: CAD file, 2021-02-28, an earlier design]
stl/EscornaflexV1_Tapa.stl
2.00 x 21.0 x 28.0

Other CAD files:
stl/wheel-l.stl

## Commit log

2021-02-28 Afegeixo STL
    [EscornaFlexV2.stl, EscornaflexSensorAsimetrico.stl, EscornaflexSensorSimetrico.stl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]
2021-02-28 move stl to stl folder
    [EscornaFlexV2.stl, EscornaflexSensorAsimetrico.stl, EscornaflexSensorSimetrico.stl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]
